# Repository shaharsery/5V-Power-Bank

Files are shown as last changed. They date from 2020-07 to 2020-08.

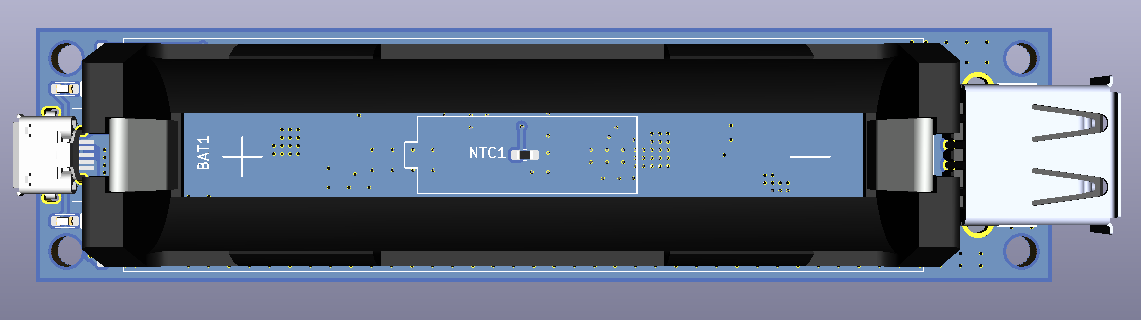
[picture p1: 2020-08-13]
Pictures/PCB TOP.png

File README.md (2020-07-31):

# 5V rechargeable power bank (Work in progress)

This project is a 5V rechargeable power bank, intended for use with 1 Li-ion / Li-Pol 3.7V rechargeable battery cell.

The design supports up to 1A of charge current and up to 1A of output current.

The exact specification of this design are strongly related to the battery used and other elements such as components used, enclosure, wall adapter etc. 

This is an open source hardware (OSHW) project, licensed under the Creative Commons Attribution Share Alike 4.0 International license.
 
For more information read the LICENSE file in the master branch, and visit [creativecommons.org](https://creativecommons.org/)

**Please note that this project has not yet been manufactured or tested! USE AT YOUR OWN RISK!**

## Specifications 

#### Nominal ratings and parameters: 

Input Voltage: 5V

Output Voltage: 5V

Battery Cell: Li-ion / Li-Pol 3.7V 

Charge Current: 1A MAX (Adjustable)

Output Current: 1A MAX

#### Features:

The features below are based on the full BOM (without NC components), changing values of components and / or unplacing components may cause unintended behaviors.

\- Input connectors: USB Type-B Micro, solder pads.

\- Output connectors: USB Type-A port, solder pads. 

\- Battery cell protections: Overcharge voltage, overdischarge voltage, overcharge current, overdischarge current, over-temperature operation, ESD protection and reverse polarity protection.

** THIS DOESN'T MEAN NOTHING CAN GO WRONG, ALWAYS MAKE SURE YOU CONNECTED EVERYTHING CORRECTLY, BATTERIES CAN EXPLODE, BURN AND HARM YOU IF NOT PROPERLY USED **

\- Adjustable charge current by changing resistor value (R5)

\- 2 indication LEDs:

- Green LED to indicate charge completed (the green LED will turn off once the battery cell entered 2nd charge cycle).
	
- Blue LED to indicate input power to the PCB. 

Both LEDs will turn off when the power bank is removed from the wall adapter.

\- If the device is connected to a wall adapter a battery and a load, the load will be powered from the wall adapter and the battery will keep on charging, this might not work properly if the wall adapter rated current is not high enough (for MAX currents, the wall adapter should be capable of driving at least 2A)

## Notes

\- The design was created as an entry level design project, it was designed to allow for others to learn, work with and create.
 I wanted to keep the design pretty simple and to make it 'hand-solderable', that's why all passive components' packages are 0603 or larger and all ICs have lead pins,
 that way all components can be soldered using a solder iron and some basic skills.
 
 \- Through the design process I was aiming for the use of 18650 Li-ion battery cells, though it should work with any Li-ion / Li-Pol 3.7V battery, I plan on testing other battery cell packages once I'll have the PCBs for prototyping.
 
 \- Though all the components used in this project can be easily sourced from Digi-Key and Mouser, I tried to use components that can also be sourced through LCSC, Ebay or AliExpress, try to find a reliable distributor that suits your costs and needs.
 
 \- A lot of modifications can be made to reduce the cost of this design, consider the necessity of components according to your own use.
 
 \- I know some people would prefer the input connector to be Type-C, I might add another version of this design with Type-C connector later.
 
 \- I plan on creating 2 types of PCBs, one roughly the dimensions of a 18650 package, and one compact design that might be more suitable for flat battery packages.
 
 \- Please feel free to contact me if you have any question or remark, or if you found any mistake. I'll try to reply as fast as I can but I can't promise anything.
 
 \- Keep being awesome and help the OSHW community grow!

## Disclaimer

**Before you work with this project in any way, please make sure you understand what you are doing, electronics and batteries can be harmful and dangerous when not used properly.** 

**By using this project in any way you agree that you are using it at your own risk and you can't hold any one else accountable for any damage or harm that might be caused due to your use of this project.**

**Please note that this project has not yet been manufactured or tested! USE AT YOUR OWN RISK!**

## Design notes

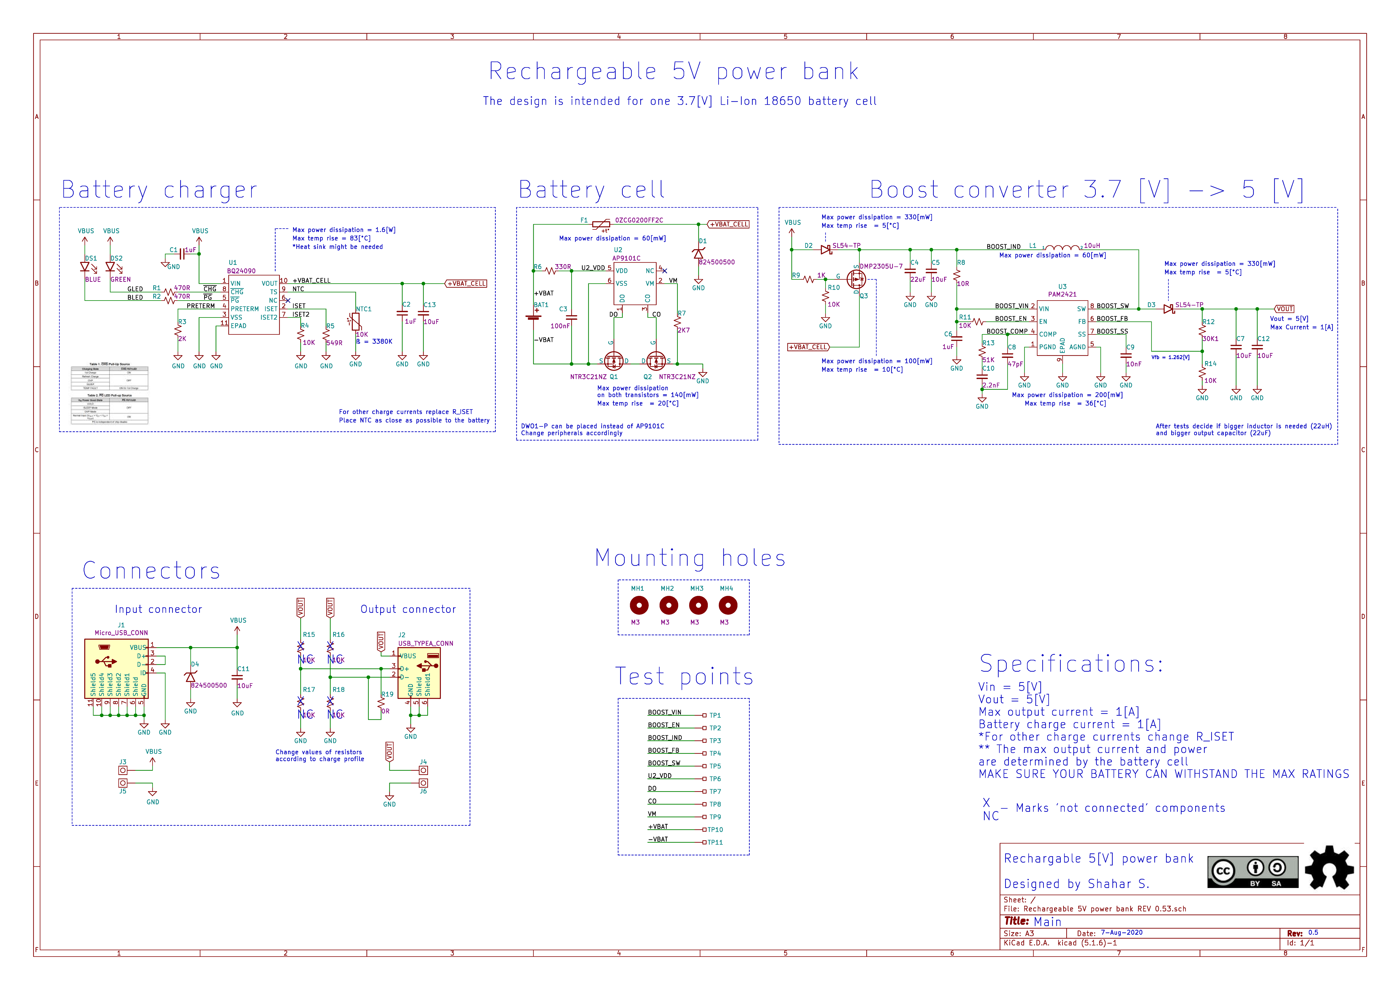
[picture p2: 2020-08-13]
Pictures/Schematic.png

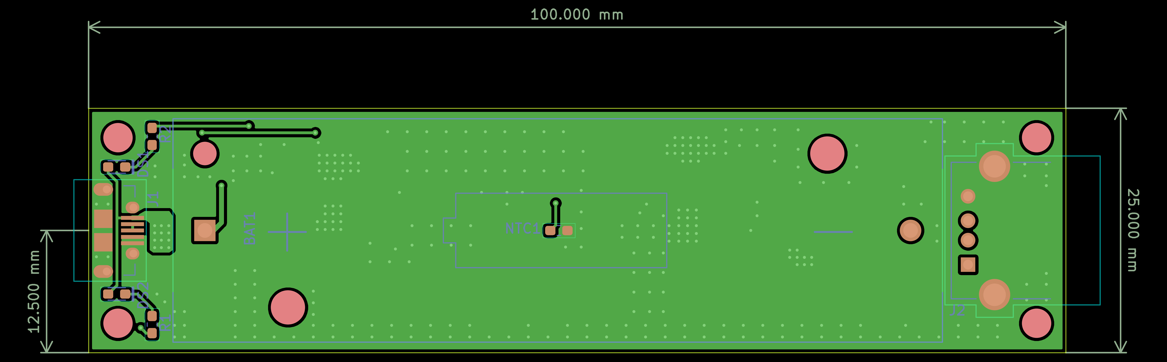
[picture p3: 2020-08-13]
Pictures/TOP layer.PNG

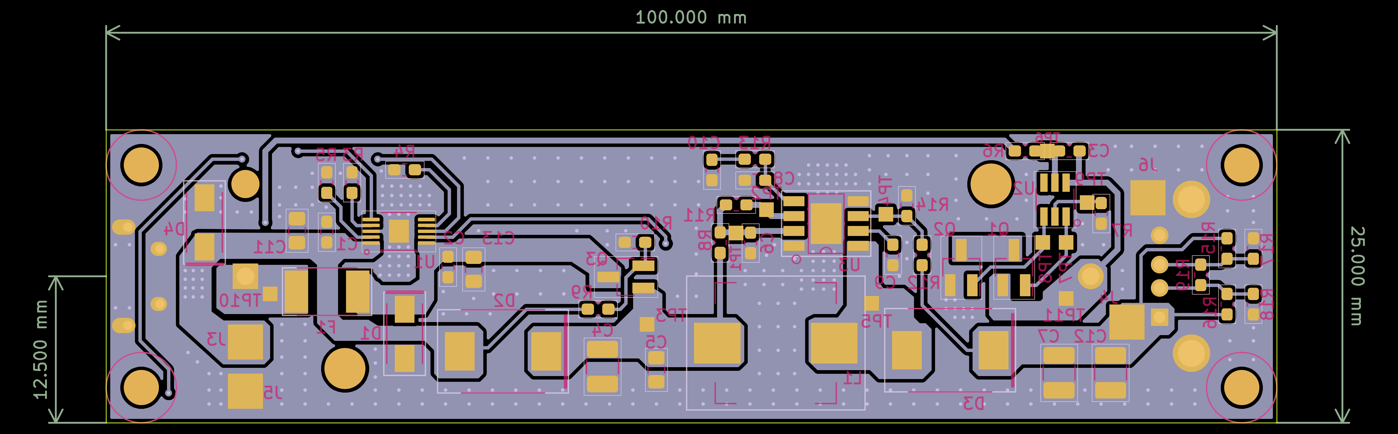
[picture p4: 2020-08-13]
Pictures/BOTTOM layer.PNG

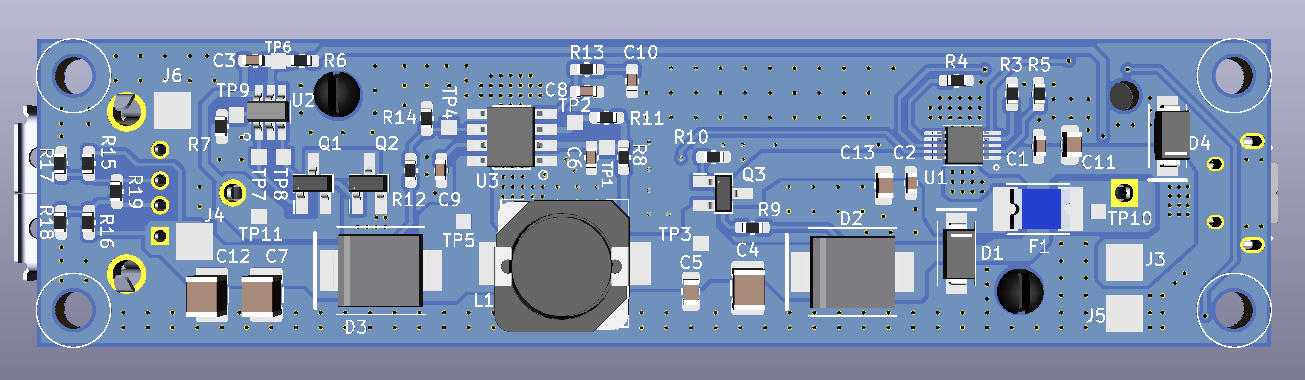
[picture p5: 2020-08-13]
Pictures/PCB BOTTOM.png

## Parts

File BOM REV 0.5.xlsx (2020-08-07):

Rechargeable 5V power bank REV 0.5 - BOM
Refdes | QTY | Name | Value | Manufacturer | Manufacturer PN | Price for 1 | Price for 100 | Footprint | Link | Datasheet | Assembly | Bom Ignore
BAT1 | 1 | BAT_18650_HOLDER_SMD | BAT 18650 | Keystone Electronics | 1042 | 3.93 | 2.73 | BATTERIES:BAT_18650_HOLDER_SMD | https://www.digikey.com/product-detail/en/keystone-electronics/1042/36-1042-ND/2745668 | https://www.keyelco.com/userAssets/file/M65p27.pdf | N/A | N/A
C3 | 1 | CAPC_100nF_0603 | 100nF | CAP CER 0.1UF 25V X7R 0603 | CC0603KRX7R8BB104 | 0.1 | 0.0224 | CAPACITORS:CACP_0603_HandSolder | https://www.digikey.com/product-detail/en/yageo/CC0603KRX7R8BB104/311-1341-1-ND/2103125 | https://www.digikey.com/en/ptm/y/yageo/multilayer-ceramic-capacitors?pn_sku=311-1341-1-ND&part_id=2103125 | N/A | N/A
C4 | 1 | CAPC_22uF_1210 | 22uF | KEMET | C1210C226K4PACTU | 0.58 | 0.2695 | CAPACITORS:CAPC_1210_HandSolder | https://www.digikey.com/product-detail/en/kemet/C1210C226K4PACTU/399-5092-1-ND/1465626 | https://content.kemet.com/datasheets/KEM_C1006_X5R_SMD.pdf | N/A | N/A
C5 | 1 | CAPC_10uF_0805 | 10uF | KEMET | C0805C106K4PACTU | 0.18 | 0.0635 | CAPACITORS:CAPC_0805_HandSolder | https://www.digikey.com/product-detail/en/kemet/C0805C106K4PACTU/399-8012-1-ND/3471735 | https://content.kemet.com/datasheets/KEM_C1006_X5R_SMD.pdf | N/A | N/A
> C1, C2, C6 | 3 | CAPC_1uF_0603 | 1uF | CL10B105MO8NNWC | CL10B105MO8NNWC | 0.1 | 0.0196 | CAPACITORS:CACP_0603_HandSolder | https://www.digikey.com/product-detail/en/samsung-electro-mechanics/CL10B105MO8NNWC/1276-6524-1-ND/5961383 | https://media.digikey.com/pdf/Data%20Sheets/Samsung%20PDFs/CL10B105MO8NNWC.pdf | N/A | N/A
C7 | 1 | CAPC_10uF_1210 | 10uF | KEMET | C1210C106M4PACTU | 0.4 | 0.1681 | CAPACITORS:CAPC_1210_HandSolder | https://www.digikey.com/product-detail/en/kemet/C1210C106M4PACTU/399-8229-1-ND/3471952 | https://content.kemet.com/datasheets/KEM_C1006_X5R_SMD.pdf | N/A | N/A
C8 | 1 | CAPC_47pF_0603 | 47pF | KEMET | C0603C470J1GACTU | 0.1 | 0.0255 | CAPACITORS:CACP_0603_HandSolder | https://www.digikey.com/product-detail/en/kemet/C0603C470J1GACTU/399-7917-1-ND/3471640 | https://api.kemet.com/component-edge/download/datasheet/C0603C470J1GACTU.pdf | N/A | N/A
C9 | 1 | CAPC_10nF_0603 | 10nF | Yageo | CC0603KRX7R9BB103 | 0.1 | 0.0174 | CAPACITORS:CACP_0603_HandSolder | https://www.digikey.com/product-detail/en/yageo/CC0603KRX7R9BB103/311-1085-1-ND/302995 | https://www.yageo.com/upload/media/product/productsearch/datasheet/mlcc/UPY-GPHC_X7R_6.3V-to-50V_18.pdf | N/A | N/A
C10 | 1 | CAPC_2.2nF_0603 | 2.2nF | KEMET | C0603C222J5RACTU | 0.1 | 0.0243 | CAPACITORS:CACP_0603_HandSolder | https://www.digikey.com/product-detail/en/kemet/C0603C222J5RACTU/399-7879-1-ND/3471602 | https://content.kemet.com/datasheets/KEM_C1002_X7R_SMD.pdf | N/A | N/A
C11 | 1 | CAPC_10uF_0603 | 10uF | Murata Electronics | GRM188R61E106KA73D | 0.36 | 0.1485 | CAPACITORS:CACP_0603_HandSolder | https://www.digikey.com/product-detail/en/murata-electronics/GRM188R61E106KA73D/490-18214-1-ND/9867943 | https://search.murata.co.jp/Ceramy/image/img/A01X/G101/ENG/GRM188R61E106KA73-01.pdf | N/A | N/A
> D1, D4 | 2 | TVS_5V_9.2V_DO214AC | 824500500 | Würth Elektronik | 824500500 | 0.27 | 0.2258 | DIODES:DO-214AC | https://www.digikey.com/product-detail/en/w%C3%BCrth-elektronik/824500500/732-9974-1-ND/5871127 | https://www.we-online.de/katalog/datasheet/824500500.pdf | N/A | N/A
> D2, D3 | 2 | Schottky_40V_5A_DO-214AB | SL54-TP | Micro Commercial Co | SL54-TP | 0.44 | 0.26 | DIODES:DO-214AB | https://www.digikey.com/product-detail/en/micro-commercial-co/SL54-TP/SL54-TPMSCT-ND/6004850 | https://www.mccsemi.com/pdf/Products/SL54~SL510(DO-214AB)-A.pdf | N/A | N/A
DS1 | 1 | LEDC_BLUE_0603 | BLUE | Würth Elektronik | 150060BS75000 | 0.16 | 0.125 | LEDS:LEDC_0603_HandSolder | https://www.digikey.com/product-detail/en/w%C3%BCrth-elektronik/150060BS75000/732-4966-1-ND/4489893 | https://www.we-online.de/katalog/datasheet/150060BS75000.pdf | N/A | N/A
DS2 | 1 | LEDC_GREEN_0603 | GREEN | Würth Elektronik | 150060VS75000 | 0.14 | 0.114 | LEDS:LEDC_0603_HandSolder | https://www.digikey.com/product-detail/en/w%C3%BCrth-elektronik/150060VS75000/732-4980-1-ND/4489904 | https://www.we-online.de/katalog/datasheet/150060VS75000.pdf | N/A | N/A
F1 | 1 | PTC_POLYFUSE_8V_2A_1812 | 0ZCG0200FF2C | Bel Fuse Inc. | 0ZCG0200FF2C | 0.19 | 0.1455 | FUSES:POLYFUSEC_1812 | https://www.digikey.com/product-detail/en/bel-fuse-inc/0ZCG0200FF2C/507-1777-1-ND/4156280 | https://www.belfuse.com/resources/datasheets/circuitprotection/ds-cp-0zcg-series.pdf | N/A | N/A
J1 | 1 | Micro_USB_CONN | Micro_USB_CONN | Molex | 475890001 | 0.78 | 0.5881 | CONNECTORS:USB-TYPE-B_CONN_PORT | https://www.digikey.com/product-detail/en/molex/0475890001/WM17143DKR-ND/1832257 | https://www.molex.com/pdm_docs/sd/475890001_sd.pdf | N/A | N/A
J2 | 1 | USB-A_CONN | USB_TYPEA_CONN | TE Connectivity AMP Connectors | 292303-1 | 1.48 | 1.1495 | CONNECTORS:USB-TYPE-A_CONN_PORT | https://www.digikey.com/product-detail/en/te-connectivity-amp-connectors/292303-1/A31726-ND/773786 | https://www.te.com/commerce/DocumentDelivery/DDEController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 | N/A | N/A
> J3-J6 | 4 | 1POS_CONN_PAD_30X30MM_H1MM | 1POS_CONN_PAD_30X30MM_H1MM | N/A | N/A | N/A | N/A | PADS:PAD_RECT_30X30 | N/A | N/A | NO | YES
L1 | 1 | INDC_10uH_CDRH104R | 10uH | Sumida America Components Inc. | CDRH104RNP-100NC | 1.64 | 1.0626 | INDUCTORS:CDRH104R | https://www.digikey.com/product-detail/en/sumida-america-components-inc/CDRH104RNP-100NC/308-1429-1-ND/956657 | http://products.sumida.com/products/pdf/CDRH104R.pdf | N/A | N/A
NTC1 | 1 | NTC_10K_3380K_0603 | 10K | Murata Electronics | NCU18XH103F60RB | 0.12 | 0.0636 | RESISTORS:RESC_0603_HandSolder | https://www.digikey.com/product-detail/en/murata-electronics/NCU18XH103F60RB/490-16279-1-ND/7363262 | https://www.murata.com/-/media/webrenewal/support/library/catalog/products/thermistor/r03e.ashx?la=en-us | N/A | N/A
> Q1, Q2 | 2 | NMOS_20V_3.6A_SOT-23-3 | NTR3C21NZ | ON Semiconductor | NTR3C21NZT1G | 0.35 | 0.162 | TRANSISTORS:SOT-23_Handsoldering | https://www.digikey.com/product-detail/en/on-semiconductor/NTR3C21NZT1G/NTR3C21NZT1GOSCT-ND/9087577 | https://www.onsemi.com/pub/Collateral/NTR3C21NZ-D.PDF | N/A | N/A
Q3 | 1 | PMOS_20V_4.2A_SOT-23-3 | DMP2305U-7 | Diodes Incorporated | DMP2305U-7 | 0.39 | 0.1382 | TRANSISTORS:SOT-23_Handsoldering | https://www.digikey.com/product-detail/en/diodes-incorporated/DMP2305U-7/DMP2305UDICT-ND/2052810 | https://www.diodes.com/assets/Datasheets/ds31737.pdf | N/A | N/A
> R1, R2 | 2 | RESC_470R_0603 | 470R | Yageo | RC0603JR-07470RL | 0.1 | 0.0077 | RESISTORS:RESC_0603_HandSolder | https://www.digikey.com/product-detail/en/yageo/RC0603JR-07470RL/311-470GRCT-ND/729738 | https://www.yageo.com/upload/media/product/productsearch/datasheet/rchip/PYu-RC_Group_51_RoHS_L_10.pdf | N/A | N/A
R3 | 1 | RESC_2K_0603 | 2K | KOA Speer Electronics, Inc. | RK73H1JTTD2001F | 0.1 | 0.0091 | RESISTORS:RESC_0603_HandSolder | https://www.digikey.com/product-detail/en/koa-speer-electronics-inc/RK73H1JTTD2001F/2019-RK73H1JTTD2001FCT-ND/9846894 | http://www.koaspeer.com/pdfs/RK73H.pdf | N/A | N/A
R5 | 1 | RESC_549R_0603 | 549R | KOA Speer Electronics, Inc. | RK73H1JTTD5490F | 0.1 | 0.0087 | RESISTORS:RESC_0603_HandSolder | https://www.digikey.com/product-detail/en/koa-speer-electronics-inc/RK73H1JTTD5490F/2019-RK73H1JTTD5490FCT-ND/9847350 | http://www.koaspeer.com/pdfs/RK73H.pdf | N/A | N/A
R6 | 1 | RESC_330R_0603 | 330R | Panasonic Electronic Components | ERJ-3EKF3300V | 0.1 | 0.0284 | RESISTORS:RESC_0603_HandSolder | https://www.digikey.com/product-detail/en/panasonic-electronic-components/ERJ-3EKF3300V/P330HCT-ND/1746761 | https://industrial.panasonic.com/cdbs/www-data/pdf/RDA0000/AOA0000C304.pdf | N/A | N/A
R7 | 1 | RESC_2K7_0603 | 2K7 | TE Connectivity Passive Product | CRGCQ0603F2K7 | 0.1 | 0.012 | RESISTORS:RESC_0603_HandSolder | https://www.digikey.com/product-detail/en/te-connectivity-passive-product/CRGCQ0603F2K7/A129693CT-ND/8577525 | https://www.te.com/commerce/DocumentDelivery/DDEController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 | N/A | N/A
R8 | 1 | RESC_10R_0603 | 10R | TE Connectivity Passive Product | CRGH0603J10R | 0.1 | 0.0175 | RESISTORS:RESC_0603_HandSolder | https://www.digikey.com/product-detail/en/te-connectivity-passive-product/CRGH0603J10R/A126395CT-ND/7603450 | https://www.te.com/commerce/alt/SinglePartSearch.do?PN=2-1879494-5&dest=stmt | N/A | N/A
R9 | 1 | RESC_1K_0603 | 1K | Yageo | RC0603JR-071KL | 0.1 | 0.0077 | RESISTORS:RESC_0603_HandSolder | https://www.digikey.com/product-detail/en/yageo/RC0603JR-071KL/311-1-0KGRCT-ND/729624 | https://www.digikey.com/en/ptm/y/yageo/chip-resistors?pn_sku=311-1.0KGRCT-ND&part_id=729624 | N/A | N/A
R12 | 1 | RESC_30K1_0603 | 30K1 | Stackpole Electronics Inc | RMCF0603FT30K1 | 0.1 | 0.0065 | RESISTORS:RESC_0603_HandSolder | https://www.digikey.com/product-detail/en/stackpole-electronics-inc/RMCF0603FT30K1/RMCF0603FT30K1CT-ND/1943087 | https://www.seielect.com/catalog/sei-rmcf_rmcp.pdf | N/A | N/A
R13 | 1 | RESC_51K_0603 | 51K | Stackpole Electronics Inc | RMCF0603FT51K0 | 0.1 | 0.0065 | RESISTORS:RESC_0603_HandSolder | https://www.digikey.com/product-detail/en/stackpole-electronics-inc/RMCF0603FT51K0/RMCF0603FT51K0CT-ND/1943102 | https://www.seielect.com/catalog/sei-rmcf_rmcp.pdf | N/A | N/A
> R4, R10, R11, R14 | 4 | RESC_10K_0603 | 10K | Stackpole Electronics Inc | RNCP0603FTD10K0 | 0.1 | 0.0273 | RESISTORS:RESC_0603_HandSolder | https://www.digikey.com/product-detail/en/stackpole-electronics-inc/RNCP0603FTD10K0/RNCP0603FTD10K0CT-ND/2240478 | https://www.seielect.com/catalog/sei-rncp.pdf | N/A | N/A
R19 | 1 | RESC_0R_0603 | 0R | Yageo | RC0603JR-070RL | 0.1 | 0.0077 | RESISTORS:RESC_0603_HandSolder | https://www.digikey.com/product-detail/en/yageo/RC0603JR-070RL/311-0-0GRCT-ND/729622 | https://www.yageo.com/upload/media/product/productsearch/datasheet/rchip/PYu-RC_Group_51_RoHS_L_10.pdf | N/A | N/A
> TP1-TP11 | 11 | TP_1.25X1.25_MM | TP_1.25X1.25_MM | N/A | N/A | N/A | N/A | TESTPOINTS:TP_RECT_1.25X1.25 | N/A | N/A | NO | YES
U1 | 1 | BQ24090DGQR | BQ24090 | Texas Instruments | BQ24090DGQR | 1.29 | 0.8385 | ICs:BQ24090DGQR_MSOP-10 | https://www.digikey.com/product-detail/en/texas-instruments/BQ24090DGQR/296-38875-1-ND/5142987 | http://www.ti.com/general/docs/suppproductinfo.tsp?distId=10 | N/A | N/A
U2 | 1 | AP9101C | AP9101C | Diodes Incorporated | AP9101CK6-ADTRG1 | 0.44 | 0.2197 | ICs:AP9101C_SOT-23-6_Handsoldering | https://www.digikey.com/product-detail/en/diodes-incorporated/AP9101CK6-ADTRG1/AP9101CK6-ADTRG1DICT-ND/5731849 | https://www.diodes.com/assets/Datasheets/AP9101C.pdf | N/A | N/A
U3 | 1 | PAM2421 | PAM2421 | Diodes Incorporated | PAM2421AECADJR | 0.87 | 0.5646 | ICs:PAM2421_SOIC-8-EP | https://www.digikey.com/product-detail/en/diodes-incorporated/PAM2421AECADJR/PAM2421AECADJRDICT-ND/4333269 | https://www.diodes.com/assets/Datasheets/PAM2421_22_23.pdf | N/A | N/A

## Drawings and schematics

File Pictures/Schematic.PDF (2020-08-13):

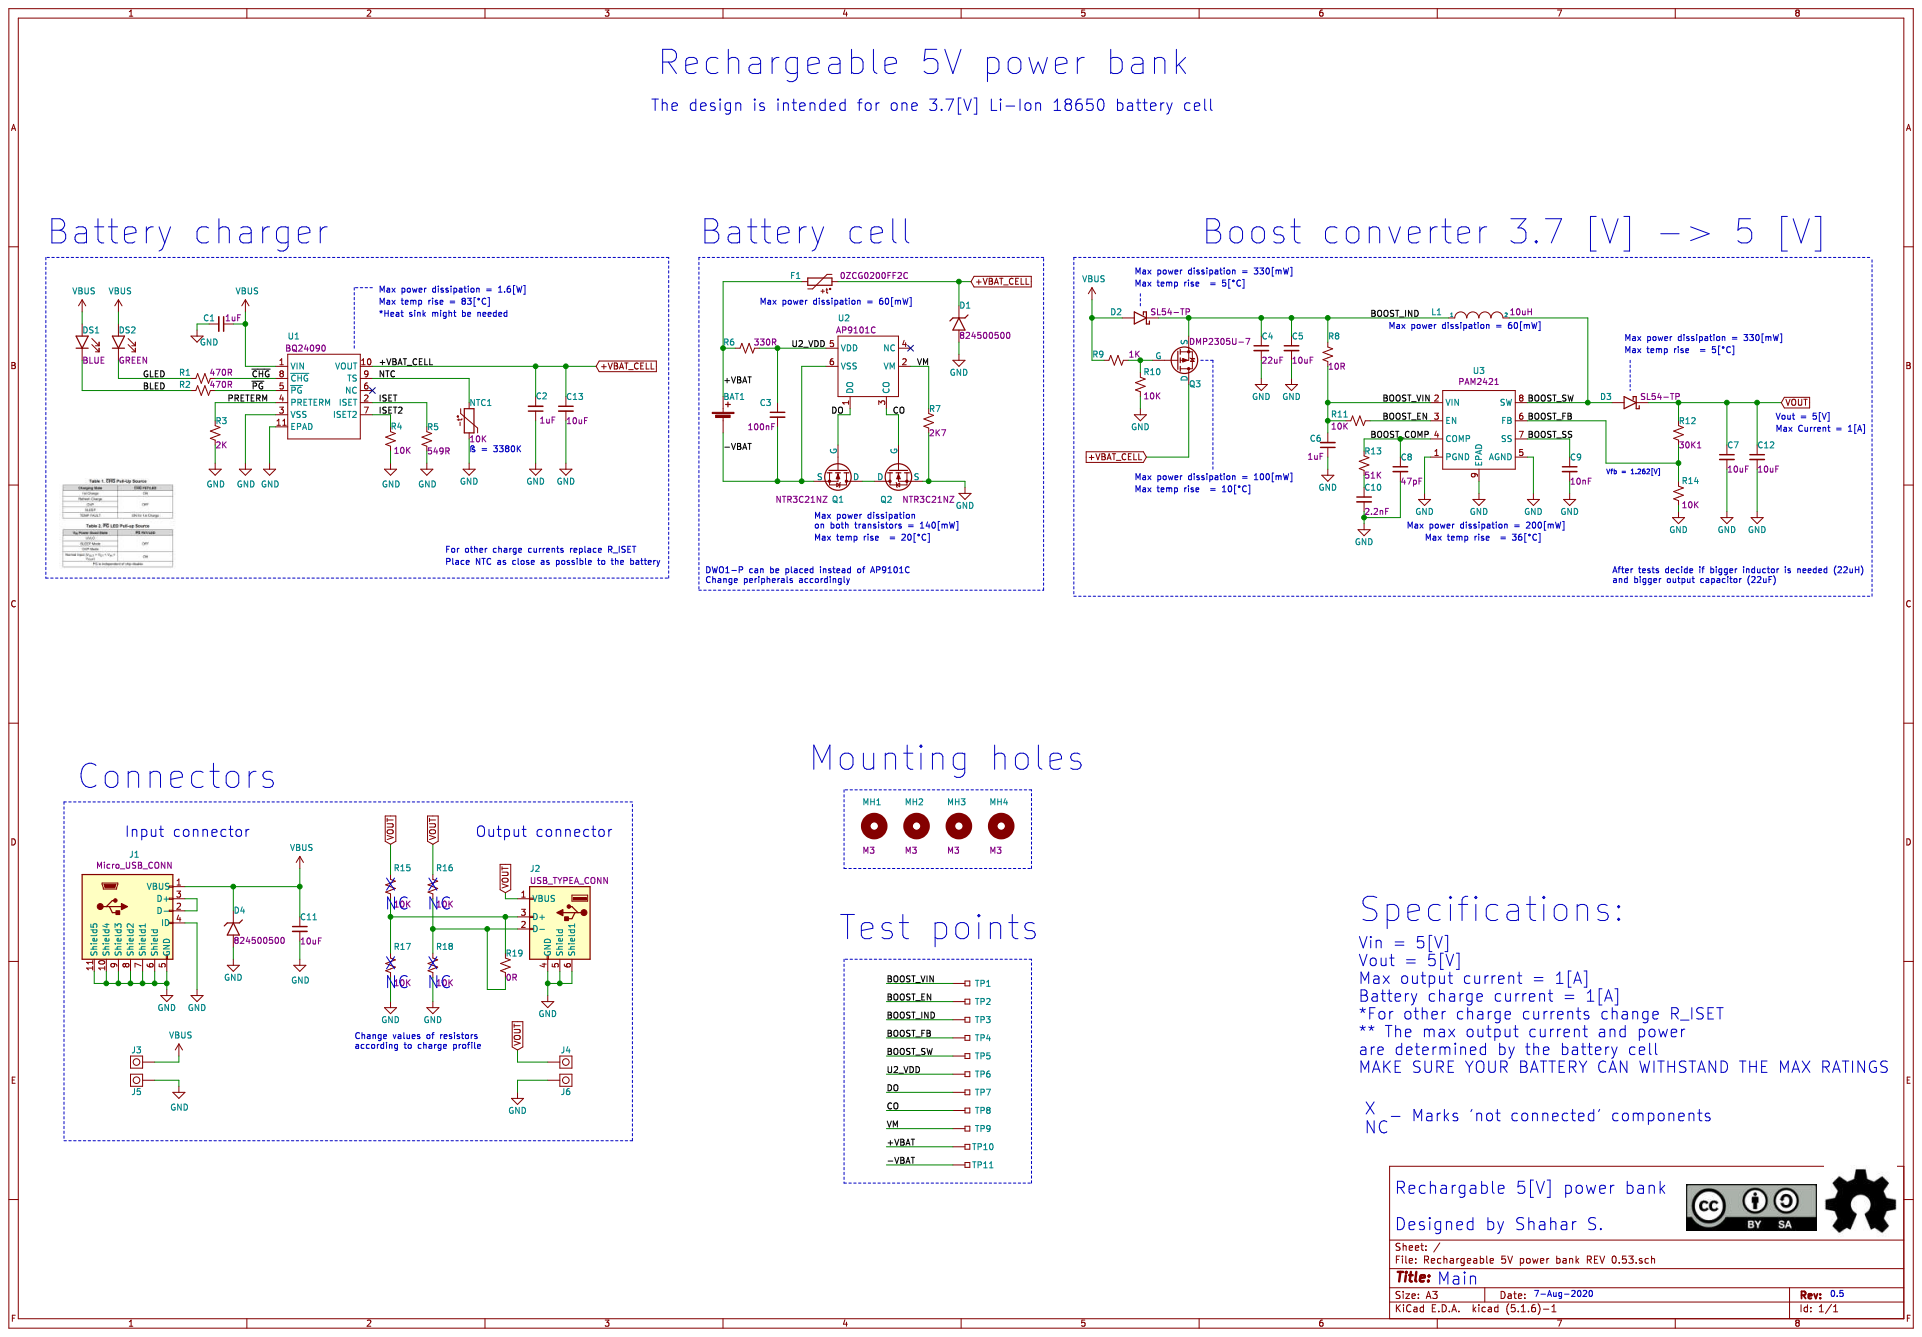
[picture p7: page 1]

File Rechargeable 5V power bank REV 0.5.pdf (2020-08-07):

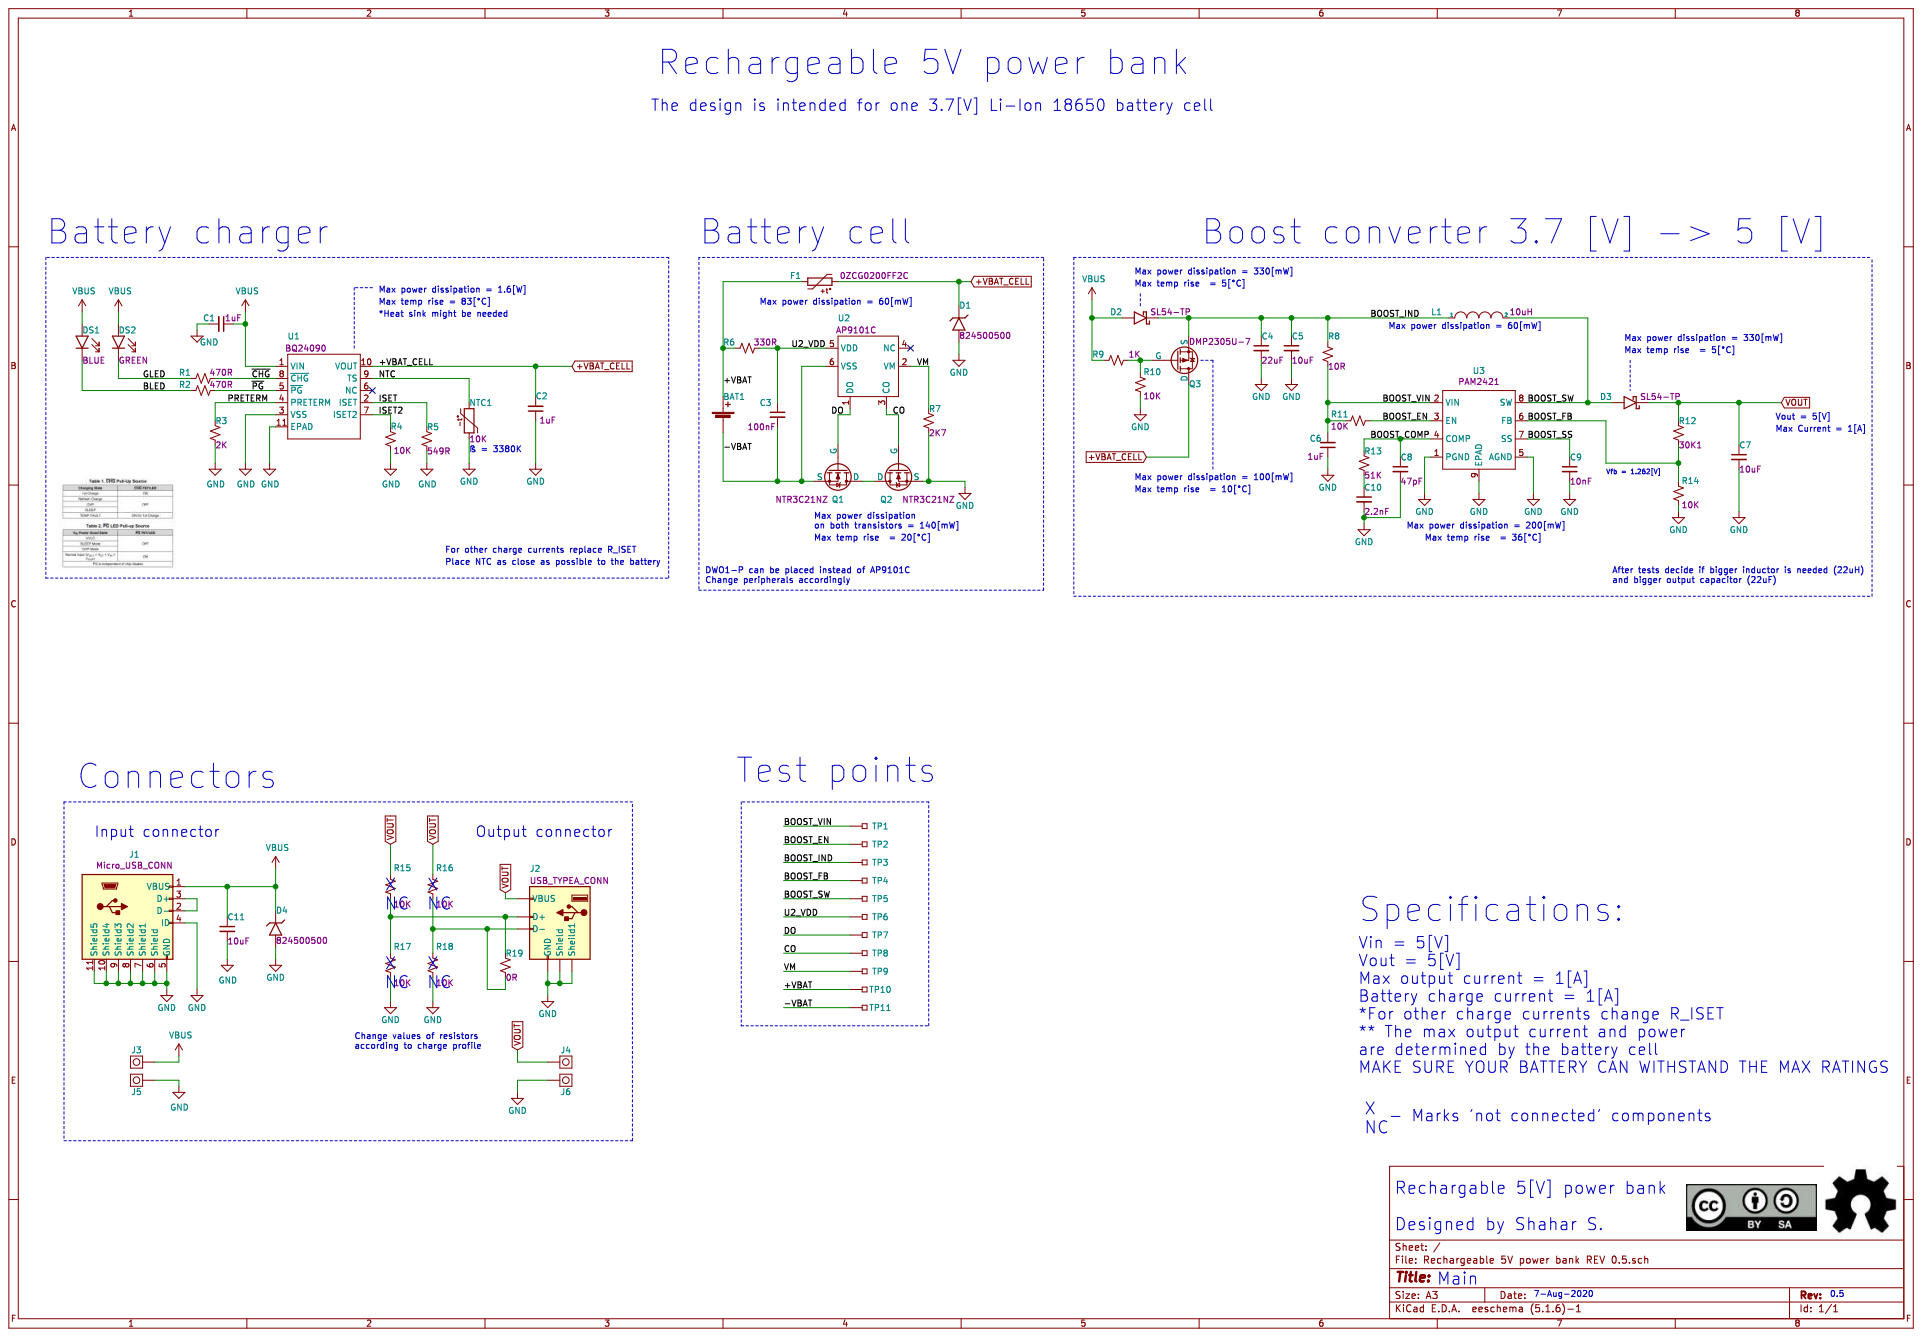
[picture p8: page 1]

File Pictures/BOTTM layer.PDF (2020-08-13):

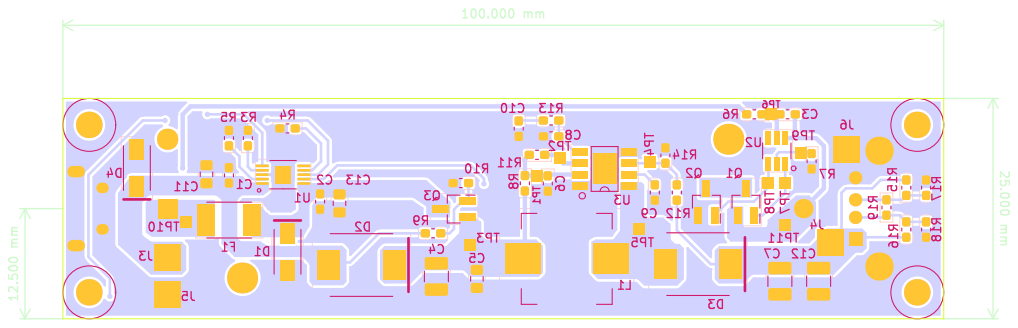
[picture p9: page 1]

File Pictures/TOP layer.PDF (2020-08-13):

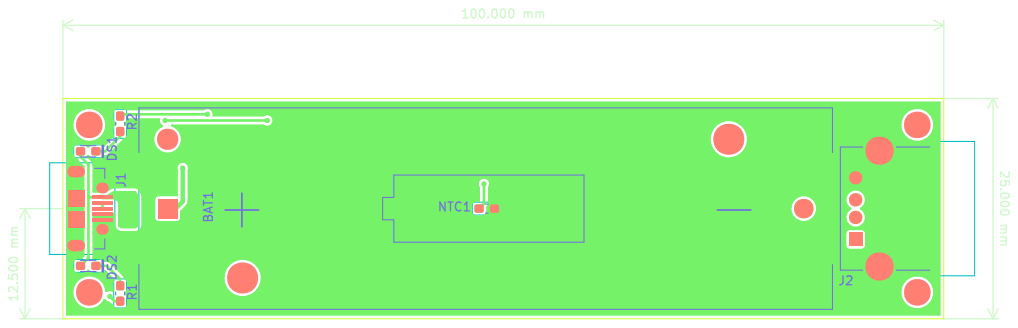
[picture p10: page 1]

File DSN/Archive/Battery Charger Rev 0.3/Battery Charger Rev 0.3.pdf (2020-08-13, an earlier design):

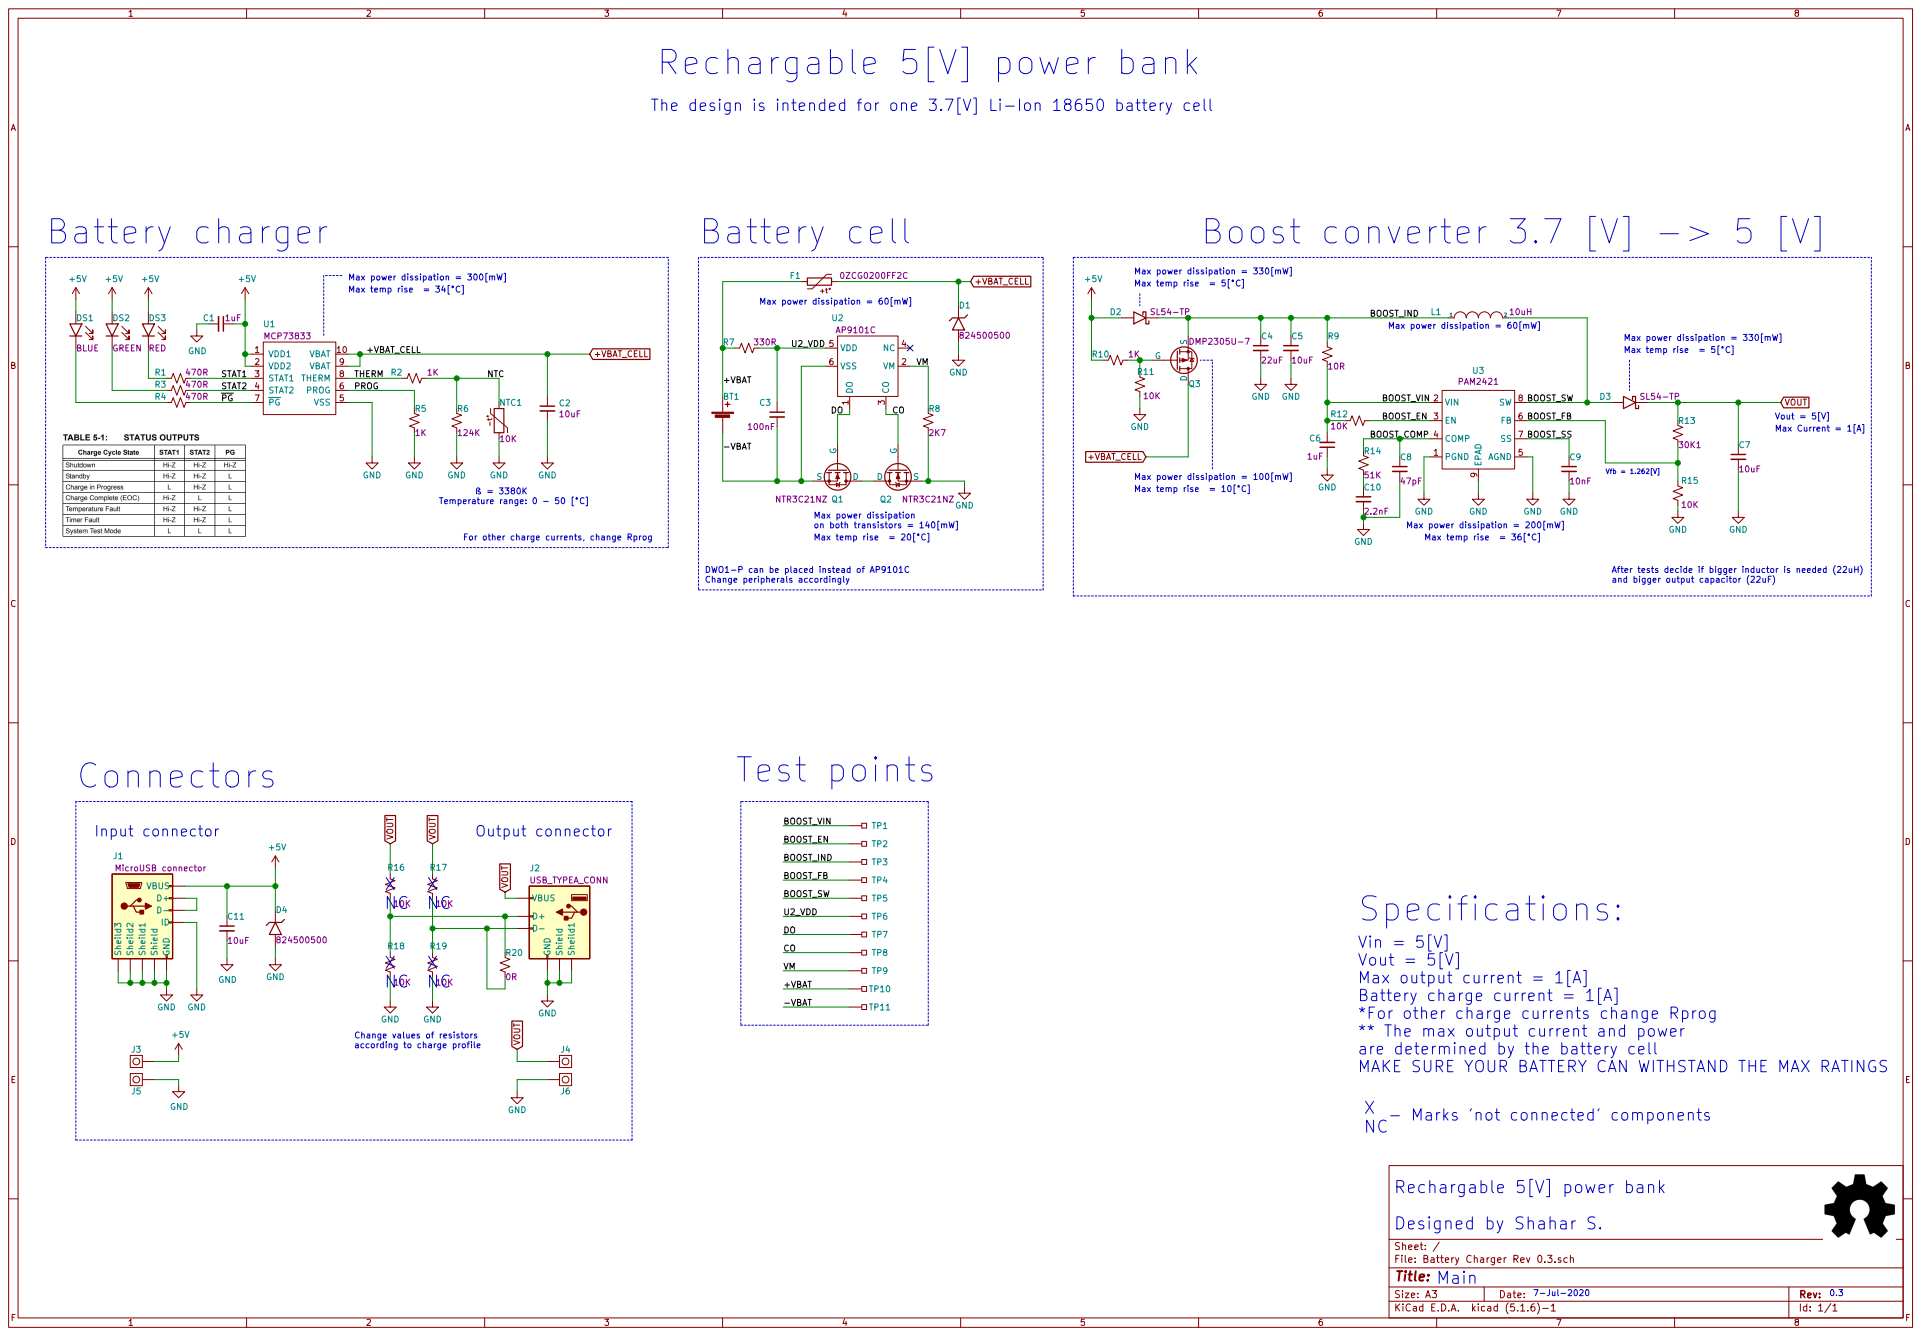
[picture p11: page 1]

The design is intended for one 3.7[V] Li-Ion 18650 battery cell

Max power dissipation = 300[mW]
Max temp rise = 34[°C]

Max power dissipation = 330[mW]
Max temp rise = 5[°C]

BOOST_IND
Max power dissipation = 60[mW]

Max power dissipation = 100[mW]
Max temp rise = 10[°C]

Max power dissipation
on both transistors = 140[mW]
Max temp rise = 20[°C]

GND
Max power dissipation = 200[mW]
Max temp rise = 36[°C]

For other charge currents, change Rprog

DWO1-P can be placed instead of AP9101C
Change peripherals accordingly

After tests decide if bigger inductor is needed (22uH)
and bigger output capacitor (22uF)

Vin = 5[V]
Vout = 5[V]
Max output current = 1[A]
Battery charge current = 1[A]
*For other charge currents change Rprog
** The max output current and power
are determined by the battery cell
MAKE SURE YOUR BATTERY CAN WITHSTAND THE MAX RATINGS

Change values of resistors
according to charge profile

File: Battery Charger Rev 0.3.sch Sheet: /

Main

7-Jul-2020 | 0.3

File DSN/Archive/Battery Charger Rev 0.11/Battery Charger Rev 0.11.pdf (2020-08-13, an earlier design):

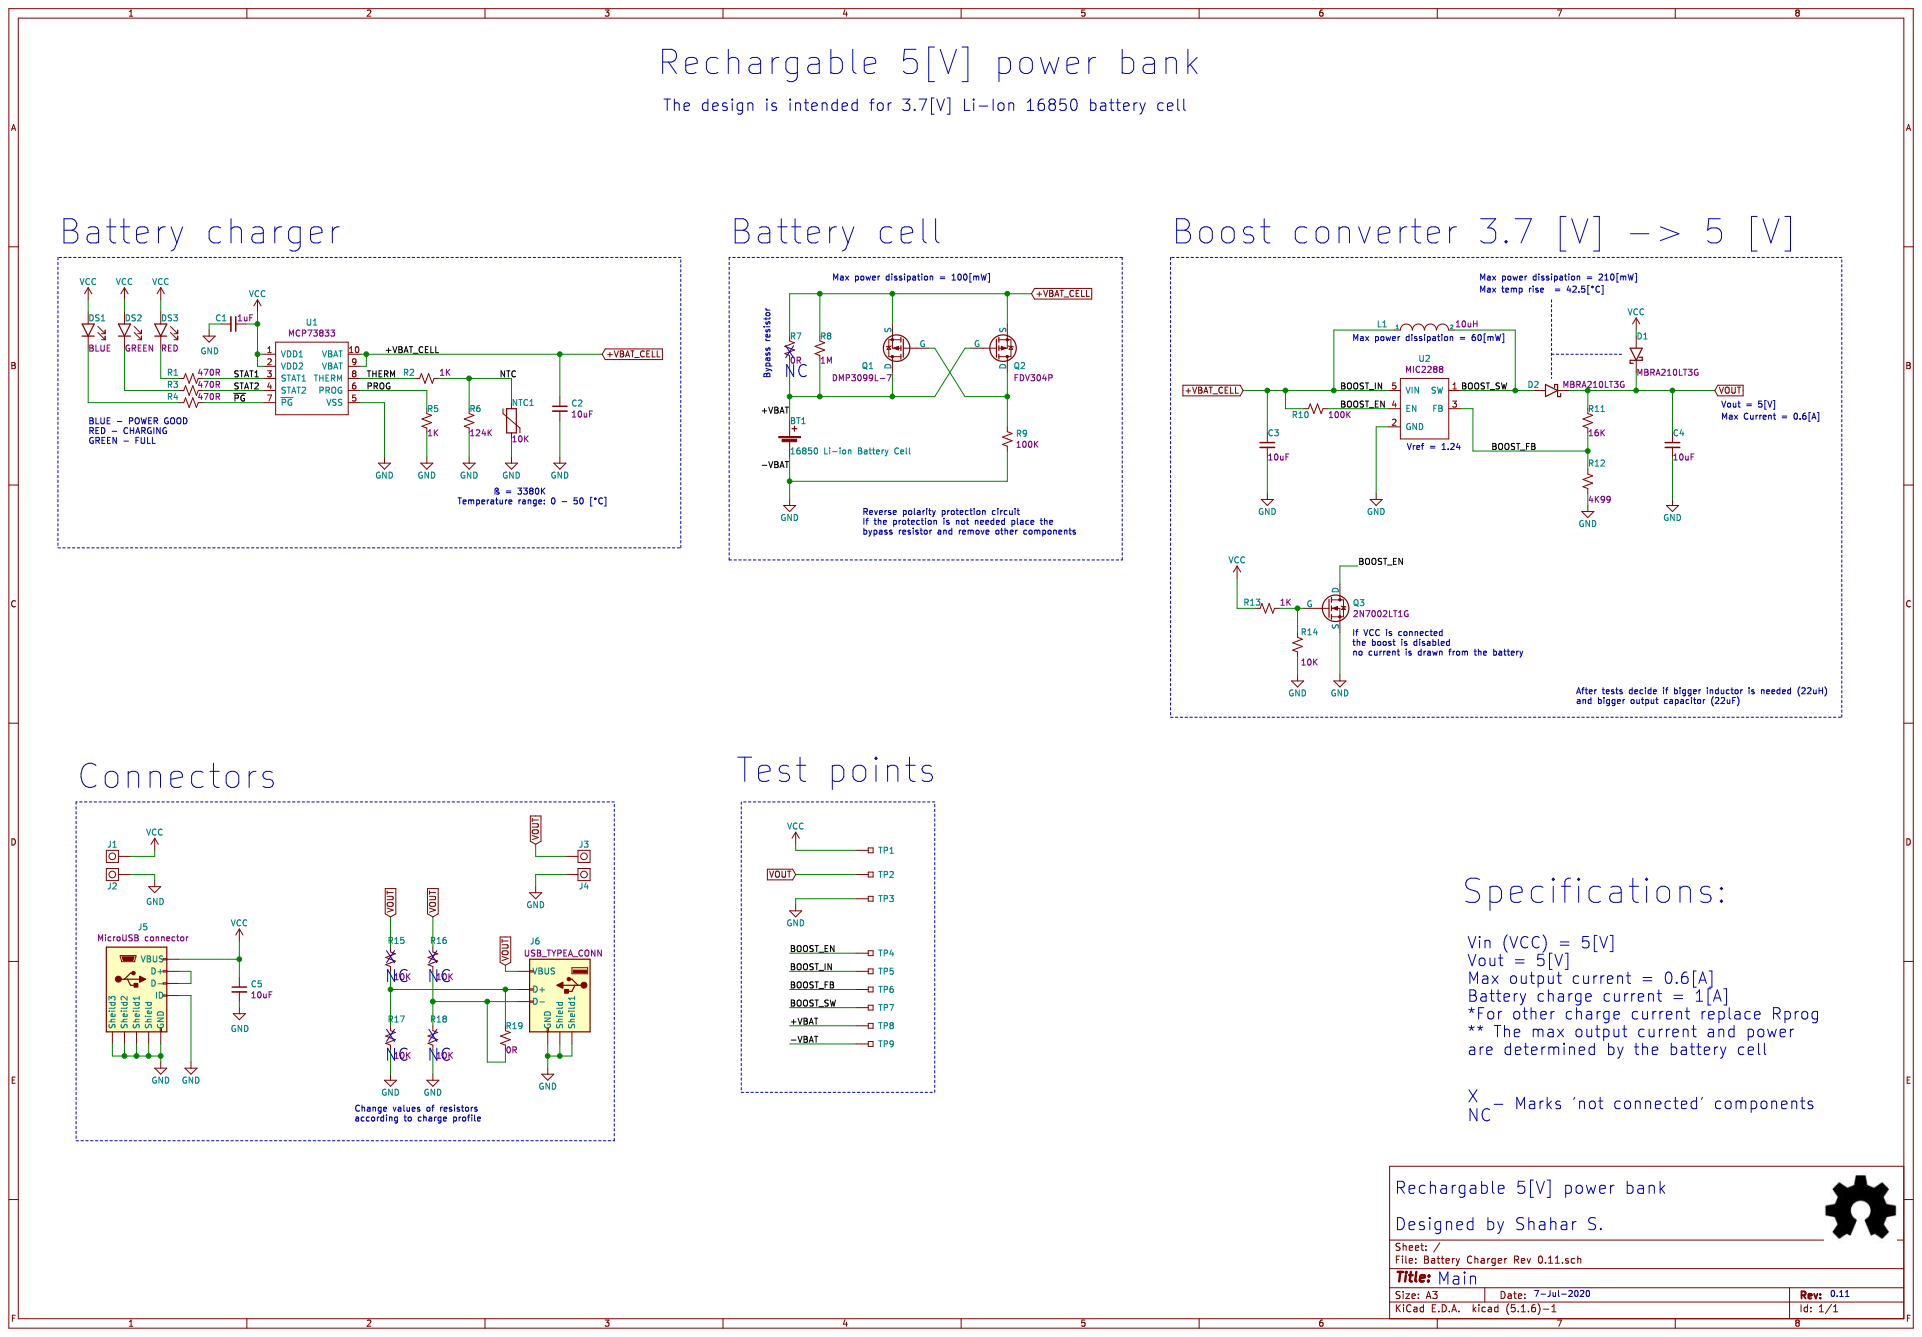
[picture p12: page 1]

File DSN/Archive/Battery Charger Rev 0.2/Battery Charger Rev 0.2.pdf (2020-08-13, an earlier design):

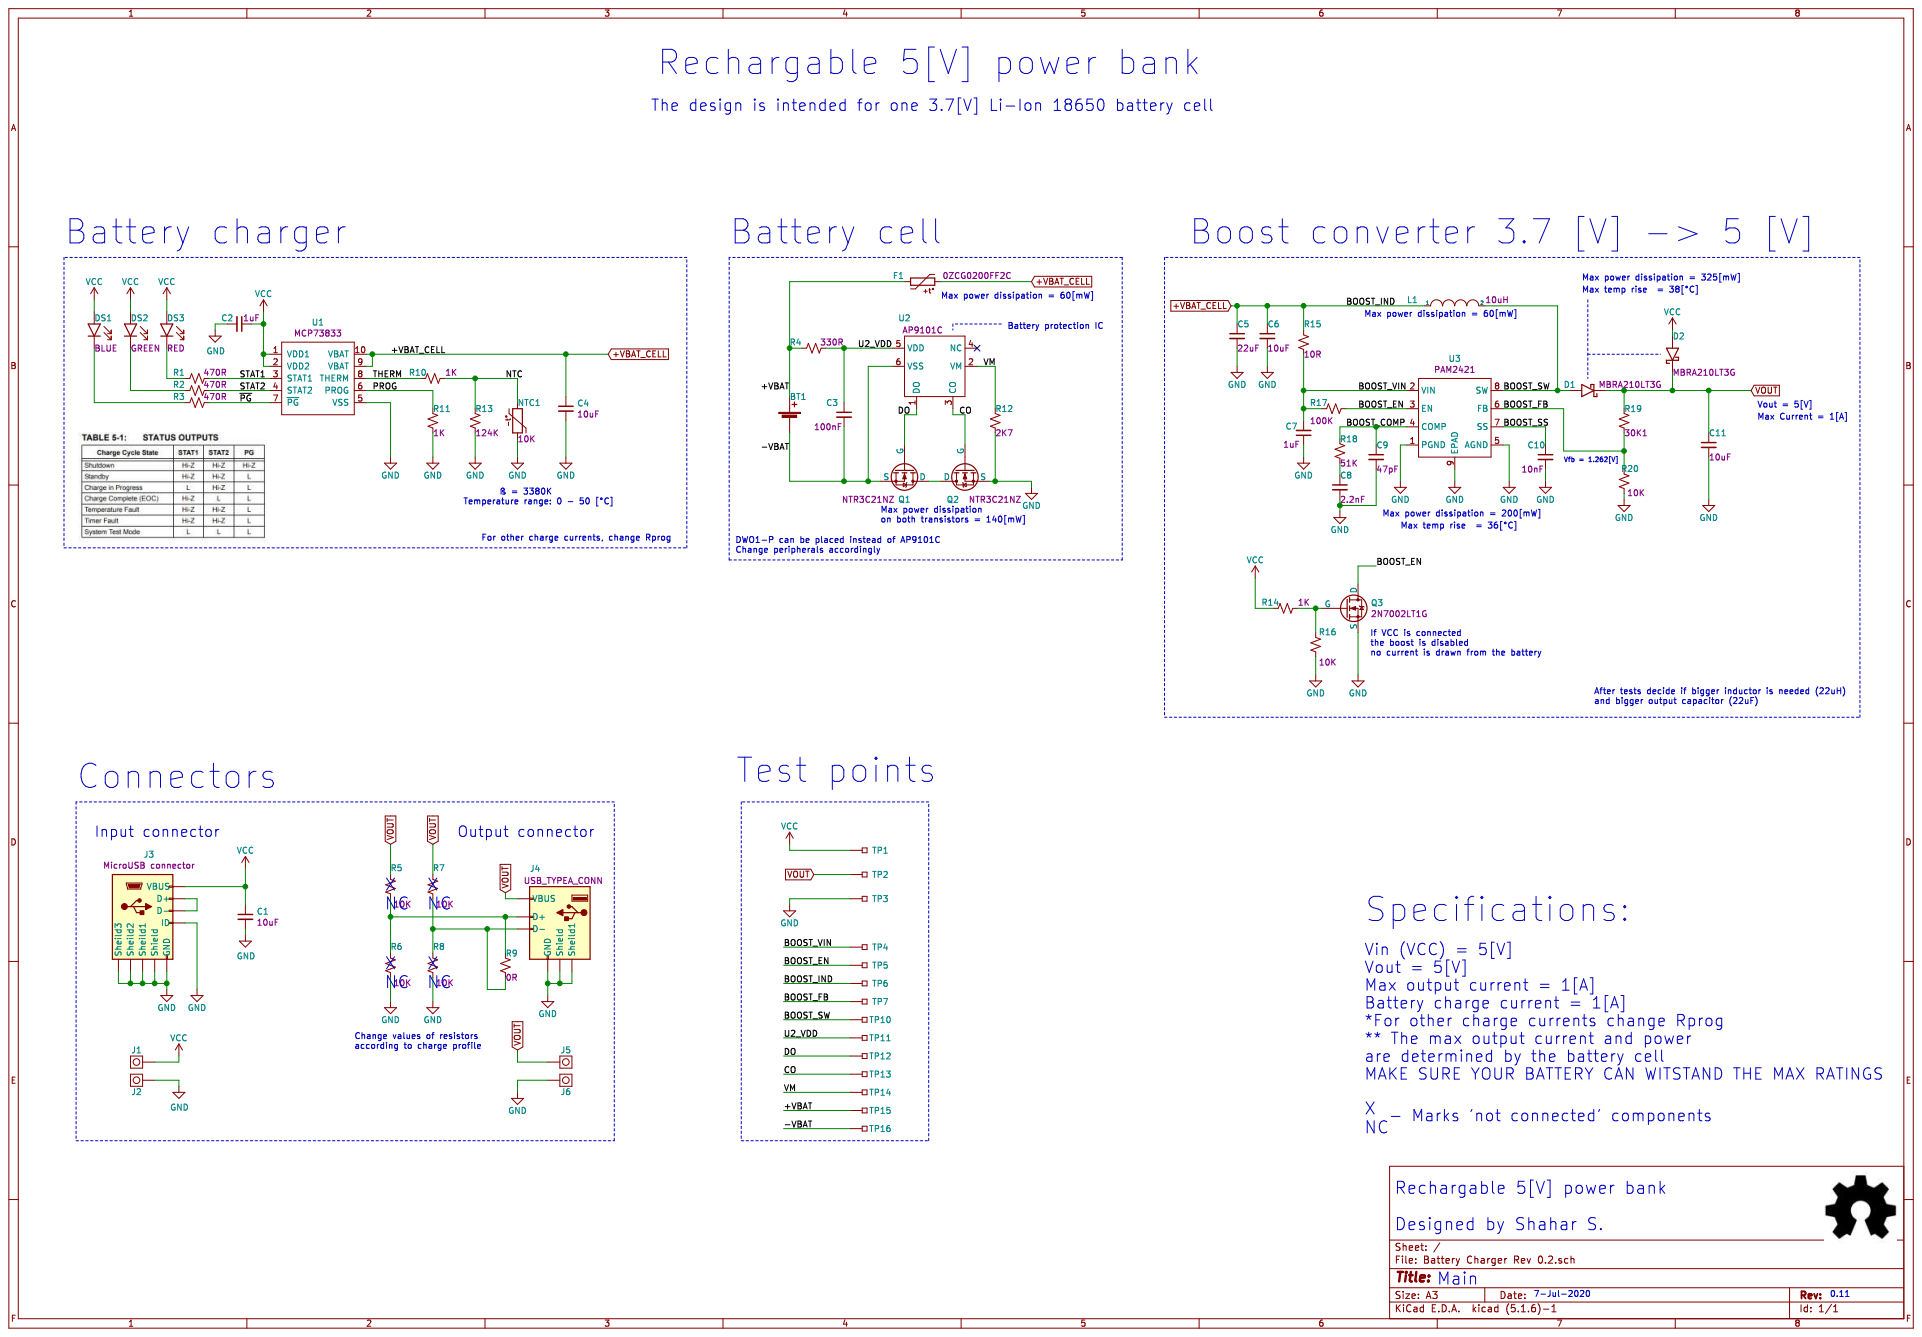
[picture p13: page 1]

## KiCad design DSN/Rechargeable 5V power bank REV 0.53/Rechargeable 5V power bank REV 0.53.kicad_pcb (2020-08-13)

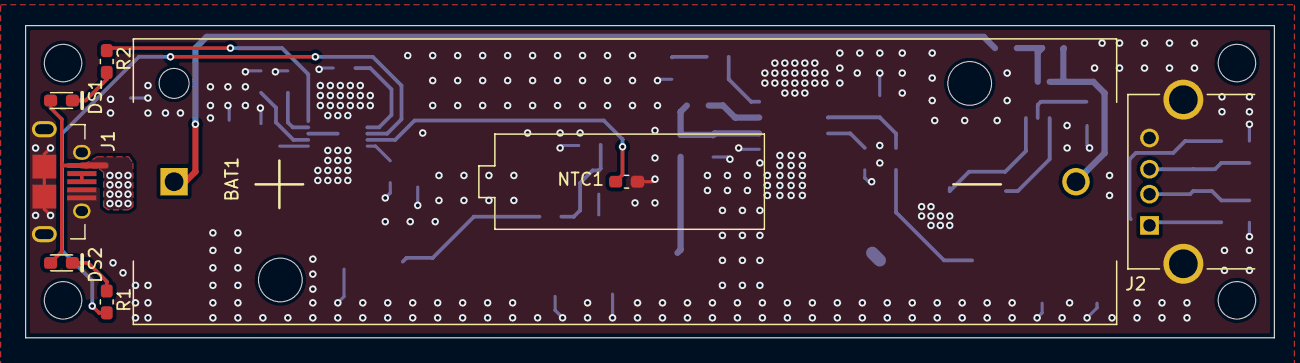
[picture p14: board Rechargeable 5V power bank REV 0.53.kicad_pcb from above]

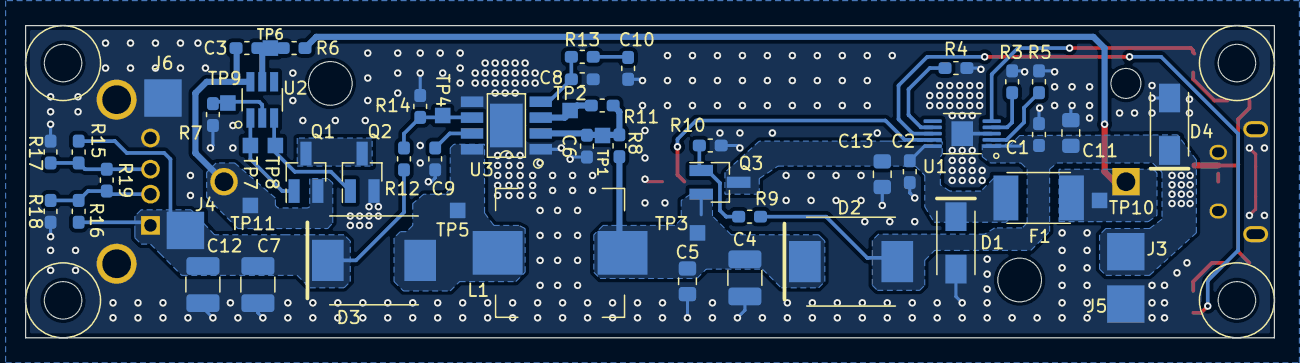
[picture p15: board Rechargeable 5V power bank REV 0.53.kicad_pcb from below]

Board: 2 copper layers, 100.0 x 25.0 mm, 69 parts (61 on the bottom side), 31 nets.

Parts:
BAT1: BAT_18650_HOLDER_THT
C1, C2, C6: CAPC_1uF_0603; CACP_0603_HandSolder
C3: CAPC_100nF_0603; CACP_0603_HandSolder
C4: CAPC_22uF_1210; CAPC_1210_HandSolder
C5, C11, C13: CAPC_10uF_0805; CAPC_0805_HandSolder
C7, C12: CAPC_10uF_1210; CAPC_1210_HandSolder
C8: CAPC_47pF_0603; CACP_0603_HandSolder
C9: CAPC_10nF_0603; CACP_0603_HandSolder
C10: CAPC_2.2nF_0603; CACP_0603_HandSolder
D1, D4: TVS_5V_9.2V_DO214AC; DO-214AC
D2, D3: Schottky_40V_5A_DO-214AB; DO-214AB
DS1: LEDC_BLUE_0603; LEDC_0603_HandSolder
DS2: LEDC_GREEN_0603; LEDC_0603_HandSolder
F1: PTC_POLYFUSE_8V_2A_1812; POLYFUSEC_1812
J1: Micro_USB_CONN; USB-TYPE-B_CONN_PORT
J2: USB-A_CONN; USB-TYPE-A_CONN_PORT
J3, J4, J5, J6: 1POS_CONN_PAD_30X30MM_H1MM; PAD_RECT_30X30
L1: INDC_10uH_CDRH104R; CDRH104R
MH1, MH2, MH3, MH4: M3C6_NP
NTC1: NTC_10K_3380K_0603; RESC_0603_HandSolder
Q1, Q2: NMOS_20V_3.6A_SOT-23-3; SOT-23_Handsoldering
Q3: PMOS_20V_4.2A_SOT-23-3; SOT-23_Handsoldering
R1, R2: RESC_470R_0603; RESC_0603_HandSolder
R3: RESC_2K_0603; RESC_0603_HandSolder
R4, R10, R11, R14, R15, R16, R17, R18: RESC_10K_0603; RESC_0603_HandSolder
R5: RESC_549R_0603; RESC_0603_HandSolder
R6: RESC_330R_0603; RESC_0603_HandSolder
R7: RESC_2K7_0603; RESC_0603_HandSolder
R8: RESC_10R_0603; RESC_0603_HandSolder
R9: RESC_1K_0603; RESC_0603_HandSolder
R12: RESC_30K1_0603; RESC_0603_HandSolder
R13: RESC_51K_0603; RESC_0603_HandSolder
R19: RESC_0R_0603; RESC_0603_HandSolder
TP1, TP2, TP3, TP4, TP5, TP6, TP7, TP8, TP9, TP10, TP11: TP_1.25X1.25_MM; TP_RECT_1.25X1.25
U1: BQ24090DGQR; BQ24090DGQR_MSOP-10
U2: AP9101C; AP9101C_SOT-23-6_Handsoldering
U3: PAM2421; PAM2421_SOIC-8-EP

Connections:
+VBAT_CELL: C2.2, C13.1, D1.K, F1.2, Q3.D, U1.10
/+VBAT: BAT1.+, F1.1, R6.2, TP10.1
/-VBAT: BAT1.-, C3.2, Q1.S, TP11.1, U2.6
/BLED: DS1.K, R2.2
/BOOST_COMP: C8.1, R13.1, U3.4
/BOOST_EN: R11.2, TP2.1, U3.3
/BOOST_FB: R12.2, R14.2, TP4.1, U3.6
/BOOST_IND: C4.1, C5.1, D2.K, L1.1, Q3.S, R8.1, TP3.1
/BOOST_SS: C9.1, U3.7
/BOOST_SW: D3.A, L1.2, TP5.1, U3.8
/BOOST_VIN: C6.2, R8.2, R11.1, TP1.1, U3.2
/CO: Q2.G, TP8.1, U2.3
/DO: Q1.G, TP7.1, U2.1
/GLED: DS2.K, R1.2
/ISET: R5.1, U1.2
/ISET2: R4.2, U1.7
/NTC: NTC1.1, U1.9
/PRETERM: R3.1, U1.4
/U2_VDD: C3.1, R6.1, TP6.1, U2.5
/VM: R7.1, TP9.1, U2.2
/~CHG: R1.1, U1.8
/~PG: R2.1, U1.5
GND: C1.2, C2.1, C4.2, C5.2, C6.1, C7.2, C8.2, C9.2, C10.2, C11.2, C12.2, C13.2, D1.A, D4.A, J1.4, J1.5, J1.6, J1.7, J1.8, J1.9, J1.10, J1.11, J2.4, J2.5, J2.6, J5.1, J6.1, NTC1.2, Q2.S, R3.2, R4.1, R5.2, R7.2, R10.1, R14.1, R17.1, R18.1, U1.3, U1.11, U3.1, U3.5, U3.9
unnamed: C10.1, R13.2
unnamed: J1.2, J1.3
unnamed: J2.2, R16.1, R18.2, R19.2
unnamed: J2.3, R15.1, R17.2, R19.1
unnamed: Q1.D, Q2.D
unnamed: Q3.G, R9.1, R10.2
VBUS: C1.1, C11.1, D2.A, D4.K, DS1.A, DS2.A, J1.1, J3.1, R9.2, U1.1
VOUT: C7.1, C12.1, D3.K, J2.1, J4.1, R12.1, R15.2, R16.2

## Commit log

2020-07-28 Uploaded DSN files
    [Battery Charger Rev 0.4.sch]
2020-08-07 UPLOAD REV 0.5
    [BOM REV 0.5.xlsx, Rechargable 5V power bank REV 0.5.sch]
2020-08-07 Update Rechargable 5V power bank REV 0.5.png
2020-08-07 Update and minor fix
    [BOM REV 0.5.xlsx, Rechargeable 5V power bank REV 0.5.sch]
2020-08-13 Updated all files
    [BOM 0.41.xlsx, BOM 0.42.xlsx, BOM 0.5.xlsx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]
